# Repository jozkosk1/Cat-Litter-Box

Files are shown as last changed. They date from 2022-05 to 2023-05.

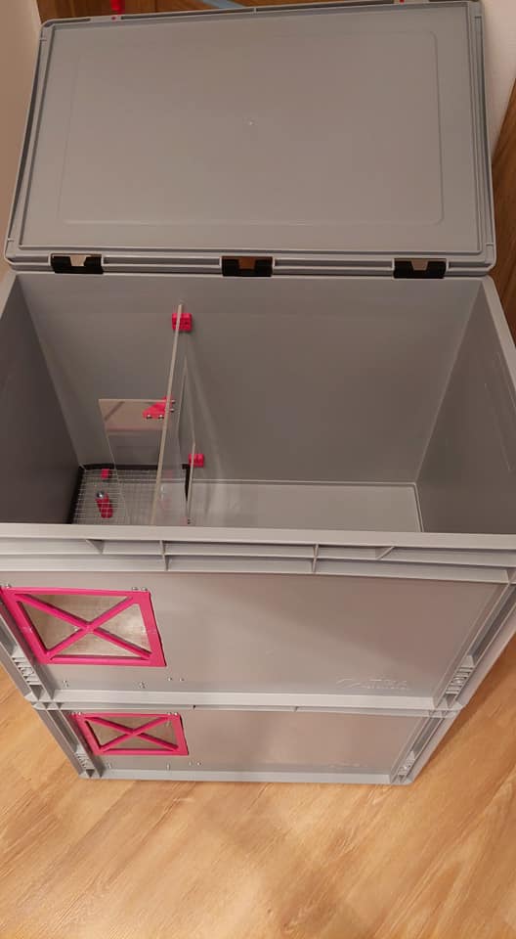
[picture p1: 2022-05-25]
Pictures/279841753_143606158199909_1568186898167949004_n.jpg

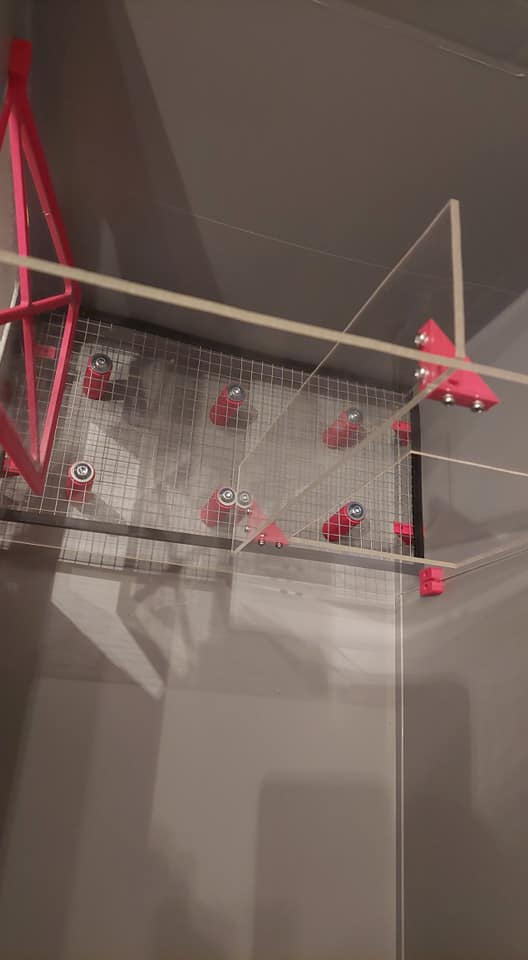
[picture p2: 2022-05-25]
Pictures/279782713_143606121533246_8742560431006277898_n.jpg

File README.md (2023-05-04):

# Cat-Litter-Box
This project is distributed under the GPL v3. <br />
Oversized 3D printed parts (doors) are optimized for the Prusa MINI printer.<br />
This project was created in cooperation with [Monelline](https://www.facebook.com/profile.php?id=100076515751206).<br />
To download the entire package, click on **CODE** > **Download ZIP**.

# Parts

 - Euro Box 60x40x42 cm  ([with](https://www.tbaplast.cz/products/euro-container-with-lid-60x40x435-cm_closed%20handles) or [without](https://www.tbaplast.cz/products/euro-container-closed-handles-60x40x42cm) lid)
 - 5mm thick plexi glass
 - Screw  DIN 7985 M3x10 - 30 pieces
 - Screw ISO 7380 M8x10 - 6 pieces
 - Nut DIN 934 M3 - 28 pieces
 - ~~Wire mesh (I used wire mesh with 10mm holes)~~ 3D printed parts: **mriezka_3D_tlac** - 2 pieces and **back** and **front** - 1 piece of each
 - Transparent office foil
 - 3D printed part: **door_bottom** - 1 piece 
 - 3D printed part: **door_top** - 1 piece
 - 3D printed part: **door_joint** - 1 piece
 - 3D printed part: **door_joint_mirror** - 1 piece
 - 3D printed part: **leg** - 6 pieces
 - 3D printed part: **plexi_holder** - 4 pieces
 - 3D printed part: **plexi_90deg_holder** - 6 pieces

# Manufacturing process

 1. Cut and drill holes in the Euro Box based on the drawings. There are also 1:1 drawings on A3 papers that you can print, cut out and use for easy marking on the box.
 2. Cut **plexi_wall_1** and **plexi_wall_2** according to the drawings. There are also 1:1 drawings.
 3. Cut the thread into **door_joint** and **door_joint_mirror** according to drawing.
 4. Cut the thread into **leg** according to drawing.
 5. Glue the **door_bottom** and **door_top with** a second glue.
 6. According to the notch in the door, cut out and glue the transparent office foil with a second glue.
 7. Install all **plexi_holder**s  on the box. 
 8. Install 4 pieces of **plexi_90deg_holder**s on the box.
 9. Screw the bolt into the thread in **door_joint** and **door_joint_mirror**.
 10. Install one of the joint on the box. 
 11. Complete the door assembly and install the second joint on the box.  
 12. Complete wall assembly (**plexi_wall_1**, **plexi_wall_2**, **plexi_90deg_holder**)
 13. ~~Cut a mesh with an approximate size of 360x185mm.~~ Assemble the printed parts of the grid.
 14. Tighten the **leg**s to the mesh with the screws.
 15. Insert mesh into the box.
 16. Insert plexi_wall assembly into the box.

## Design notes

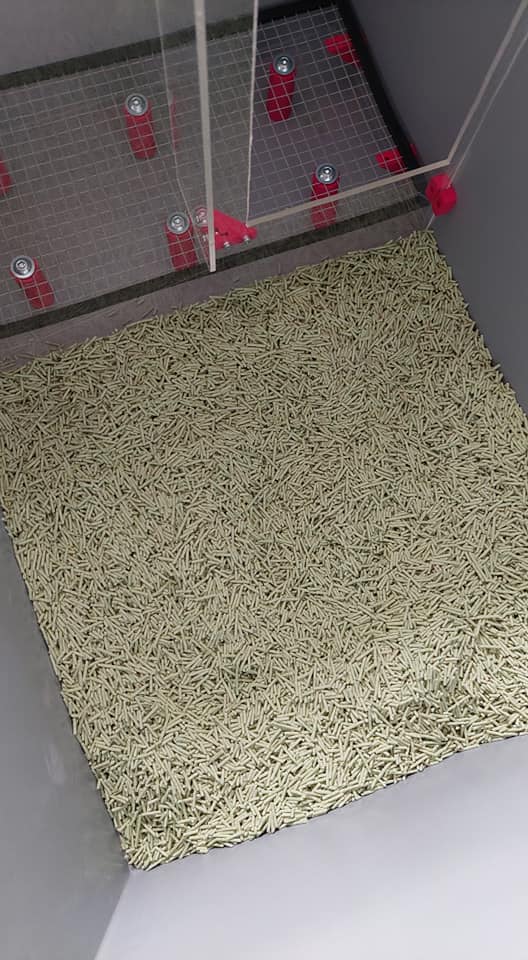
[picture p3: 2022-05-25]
Pictures/279750805_143606194866572_7029943509886688833_n.jpg

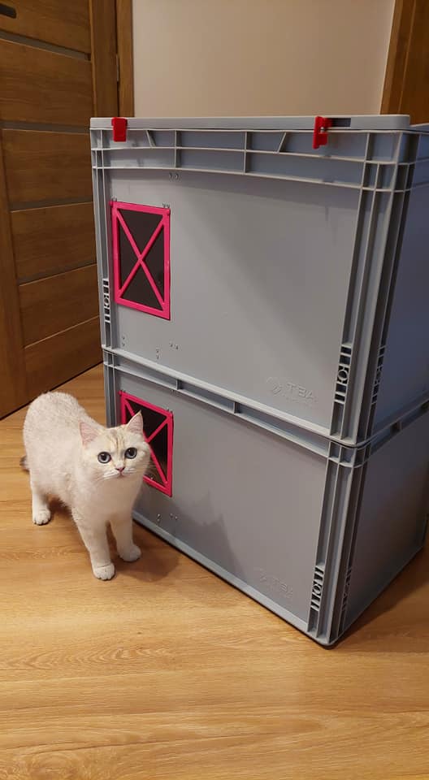
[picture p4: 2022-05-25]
Pictures/279862819_143605988199926_5207650037071910049_n.jpg

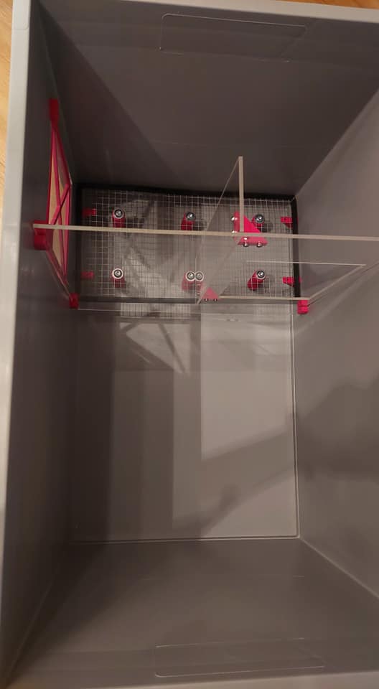
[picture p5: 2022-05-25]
Pictures/279847303_143606091533249_7798021136771881791_n.jpg

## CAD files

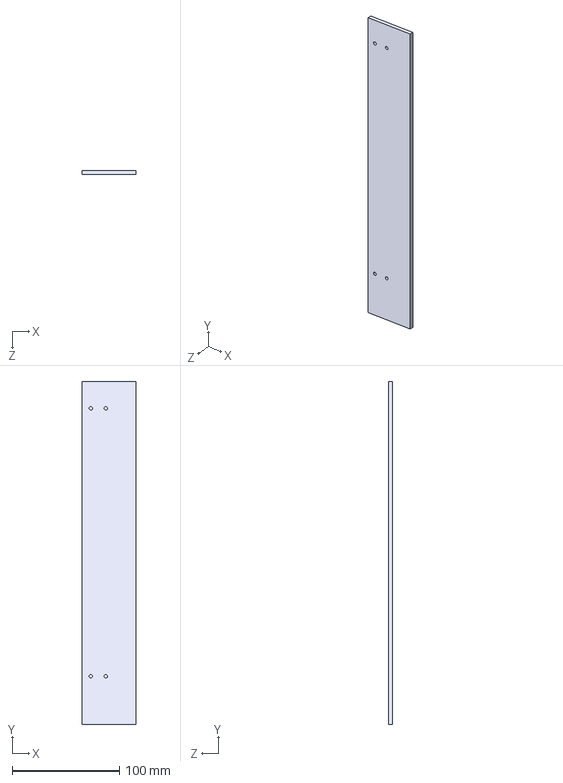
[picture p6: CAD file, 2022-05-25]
3D_data/STEP/plexi_wall_2.STEP
50.0 x 320.0 x 4.00 mm

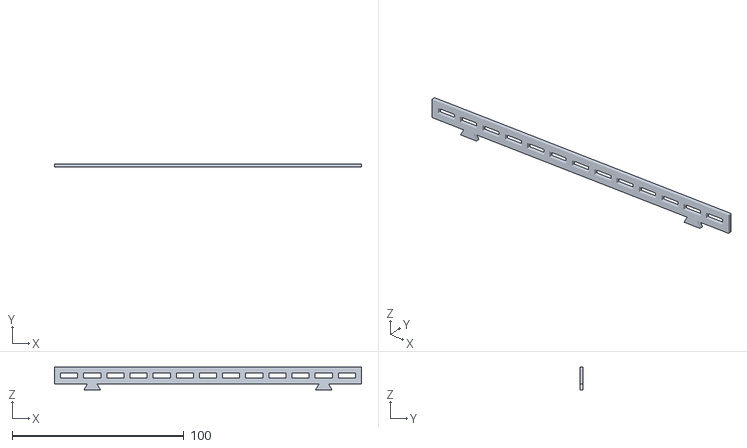
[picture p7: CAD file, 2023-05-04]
3D_data/STL/mriezka_3D_tlac_front.STL
179.0 x 2.00 x 13.4

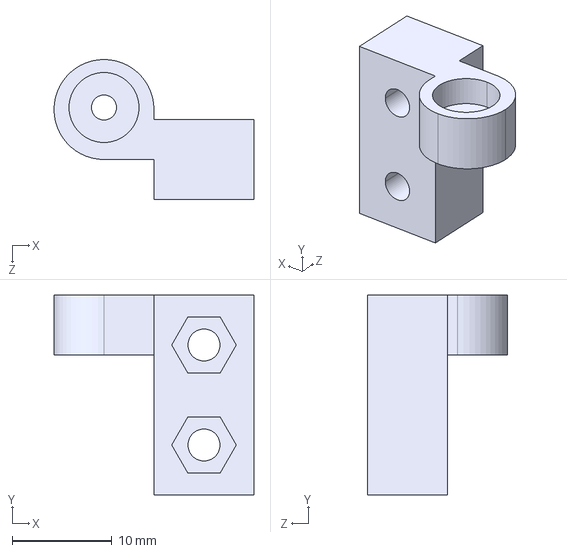
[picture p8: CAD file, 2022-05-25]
3D_data/STEP/door_joint.STEP
20.0 x 20.0 x 14.0 mm

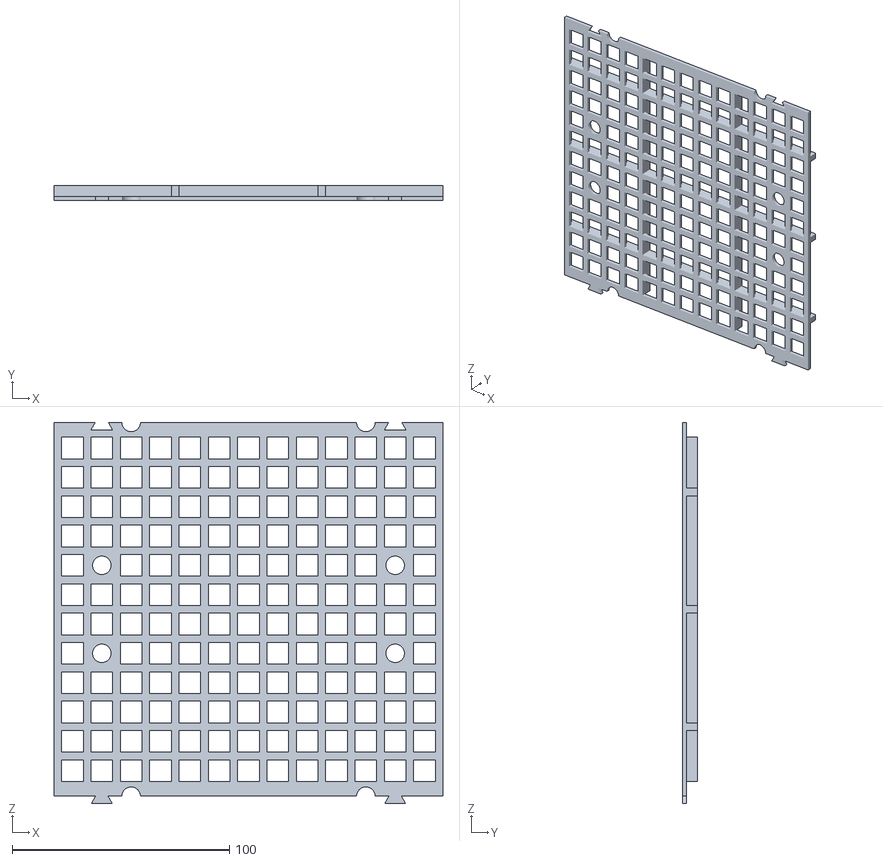
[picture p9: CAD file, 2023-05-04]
3D_data/STL/mriezka_3D_tlac.STL
179.0 x 7.00 x 175.4

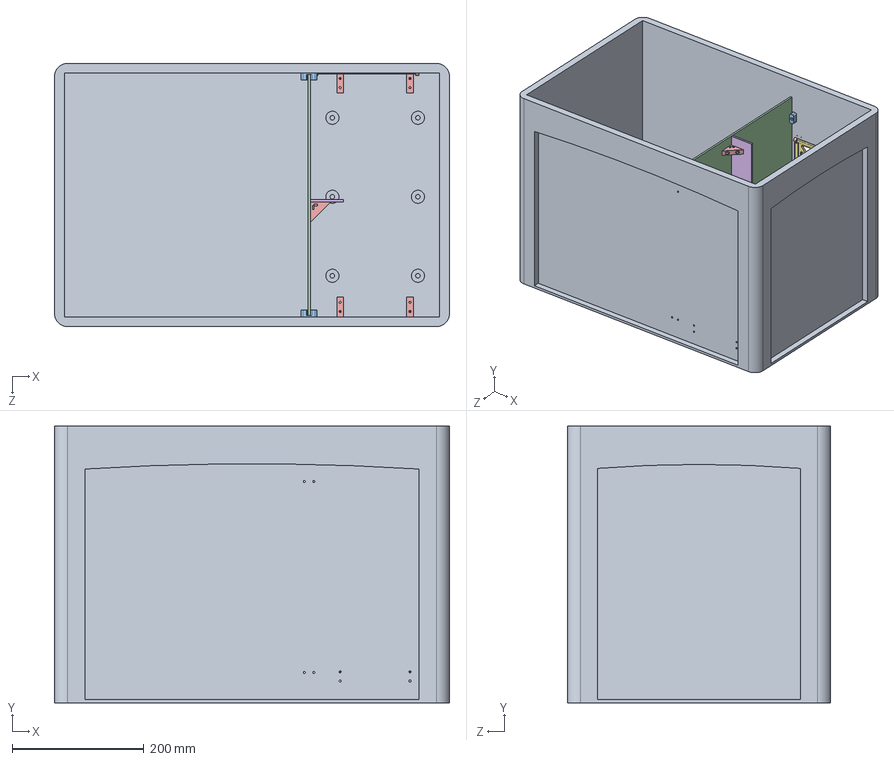
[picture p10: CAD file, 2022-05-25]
3D_data/STEP/Cat-Litter-Box.STEP
600.0 x 420.0 x 400.0 mm
Europrepravka
pant_hore
Mirrorpant_hore
plexi_holder x 4
priecka
uholnik x 6
bludisko
dvierka_2
leg x 6

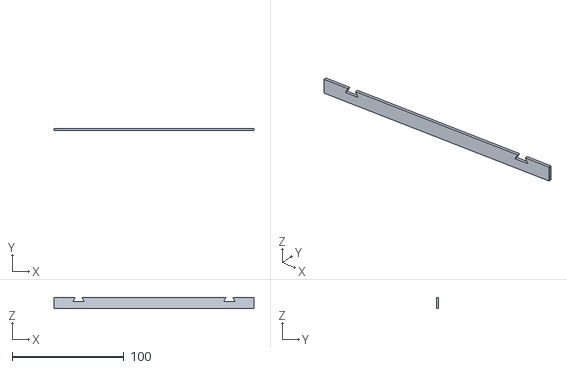
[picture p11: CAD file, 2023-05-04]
3D_data/STL/mriezka_3D_tlac_back.STL
179.0 x 2.00 x 10.0

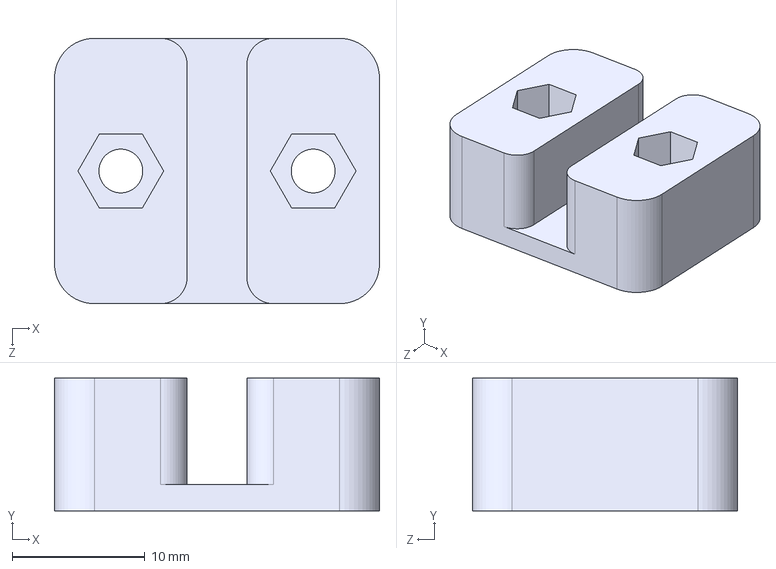
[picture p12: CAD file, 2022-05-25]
3D_data/STEP/plexi_holder.STEP
24.5 x 10.0 x 20.0 mm

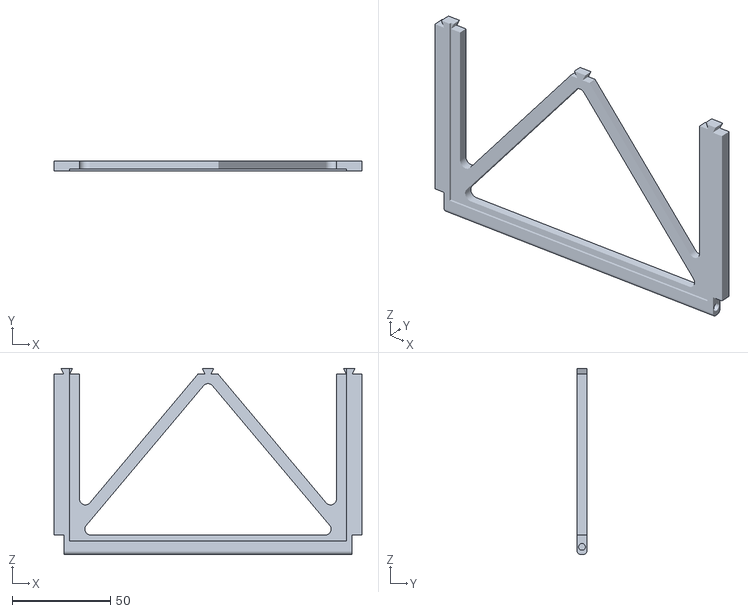
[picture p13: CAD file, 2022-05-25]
3D_data/STL/door_top.STL
157.0 x 5.00 x 95.0

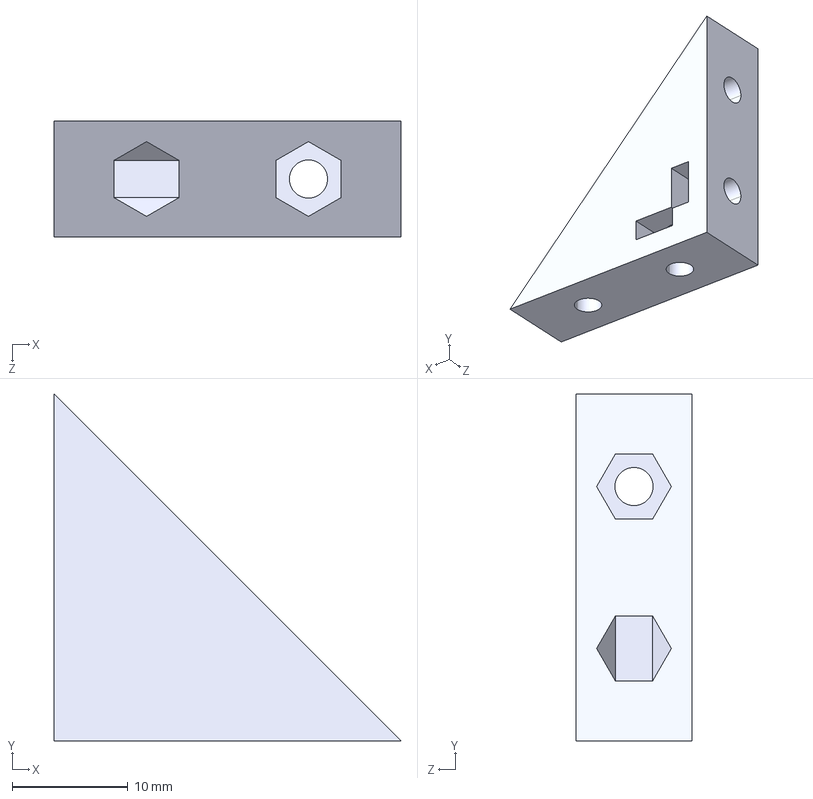
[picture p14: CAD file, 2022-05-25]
3D_data/STEP/plexi_90deg_holder.STEP
30.0 x 30.0 x 10.0 mm

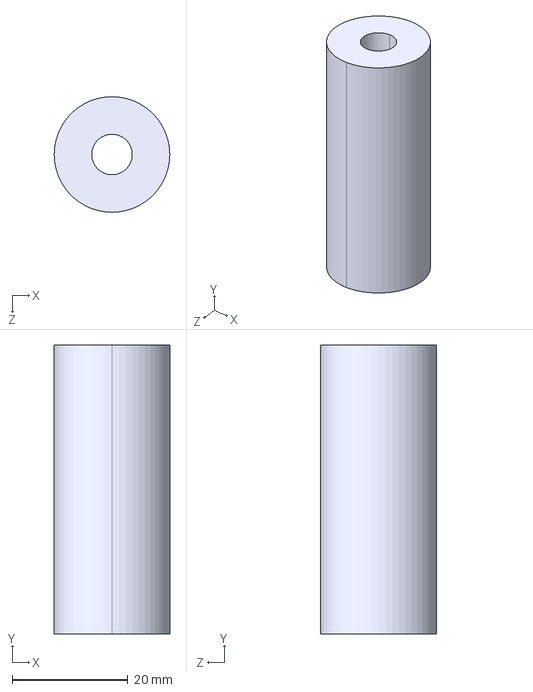
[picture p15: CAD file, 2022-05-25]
3D_data/STEP/leg.STEP
20.0 x 50.0 x 20.0 mm

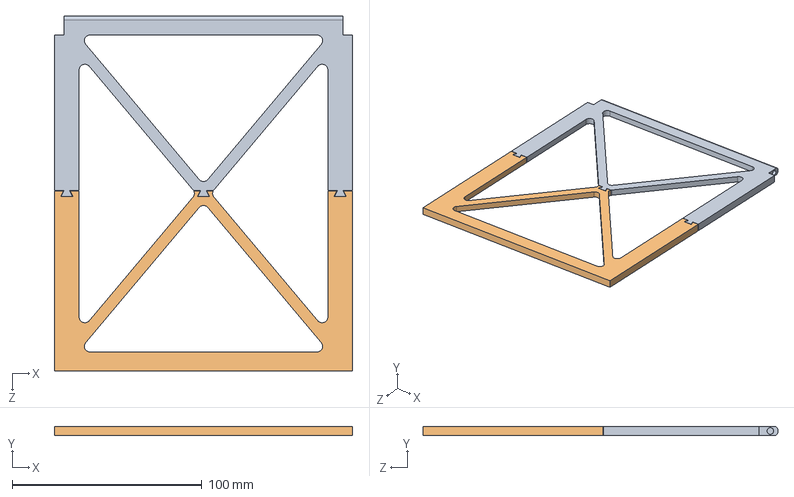
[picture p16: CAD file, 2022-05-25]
3D_data/STEP/door.STEP
157.0 x 5.00 x 187.0 mm

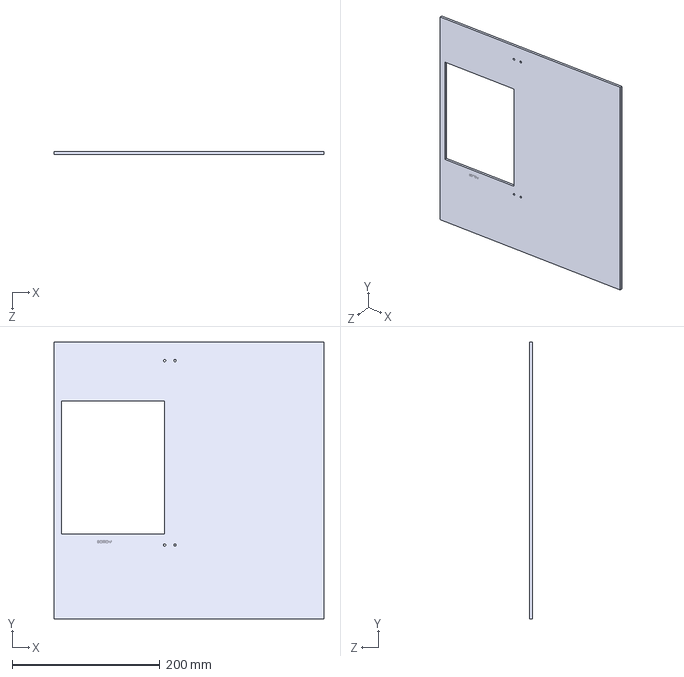
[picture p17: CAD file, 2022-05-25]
3D_data/STEP/plexi_wall_1.STEP
366.0 x 375.0 x 4.00 mm

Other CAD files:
3D_data/STL/door_bottom.STL
3D_data/STEP/door_joint_mirror.STEP
3D_data/STL/door_joint.STL
3D_data/STL/door_joint_mirror.STL
3D_data/STL/leg.STL
3D_data/STL/plexi_90deg_holder.STL
3D_data/STL/plexi_holder.STL

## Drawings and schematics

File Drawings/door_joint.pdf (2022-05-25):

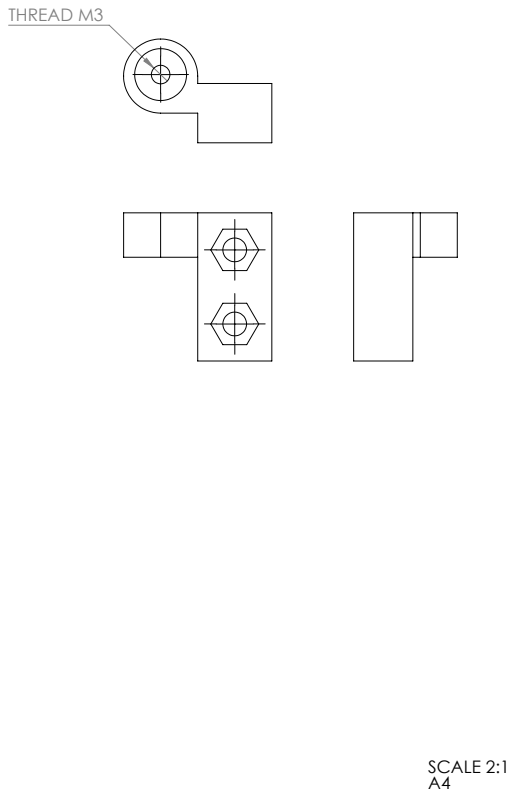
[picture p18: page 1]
THREAD M3; SCALE 2:1

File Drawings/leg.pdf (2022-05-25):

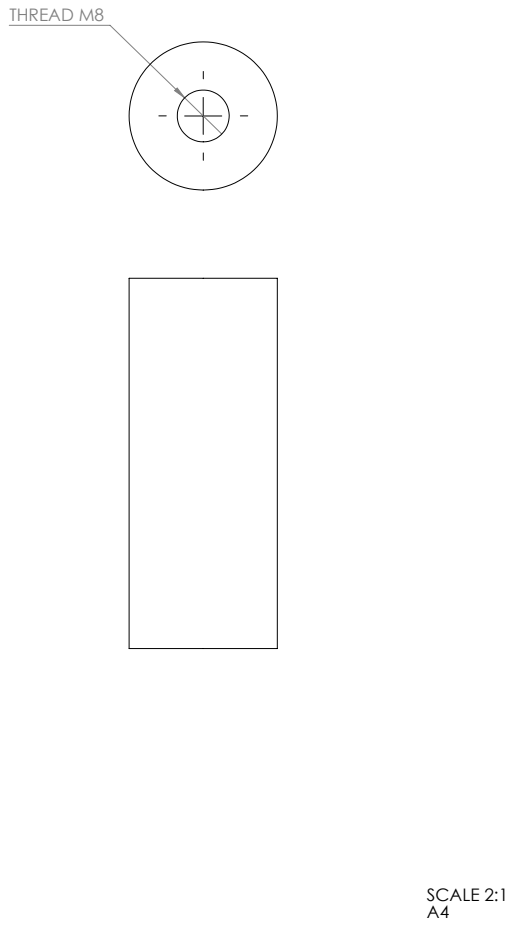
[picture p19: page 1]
THREAD M8; SCALE 2:1

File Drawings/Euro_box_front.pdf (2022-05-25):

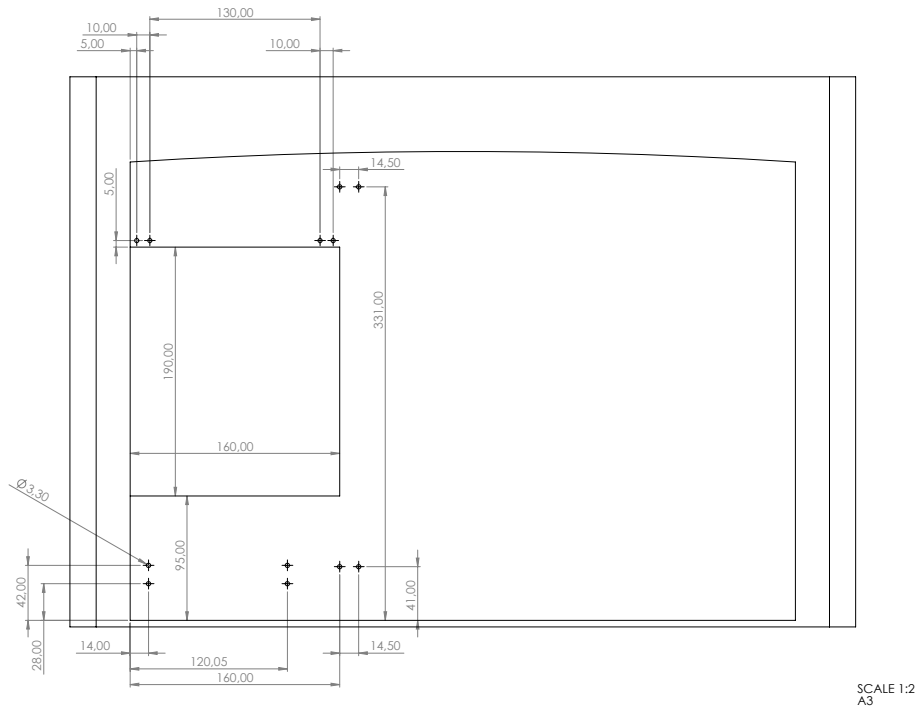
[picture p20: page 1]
SCALE 1:2

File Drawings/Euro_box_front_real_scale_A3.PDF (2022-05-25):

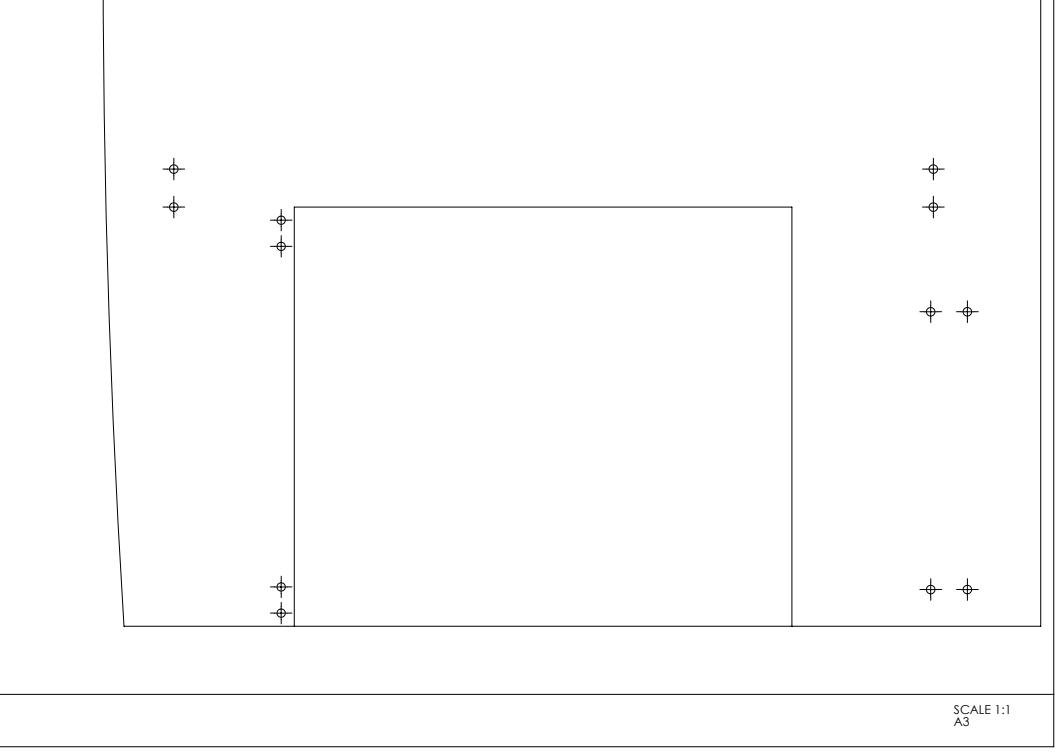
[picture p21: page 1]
SCALE 1:1

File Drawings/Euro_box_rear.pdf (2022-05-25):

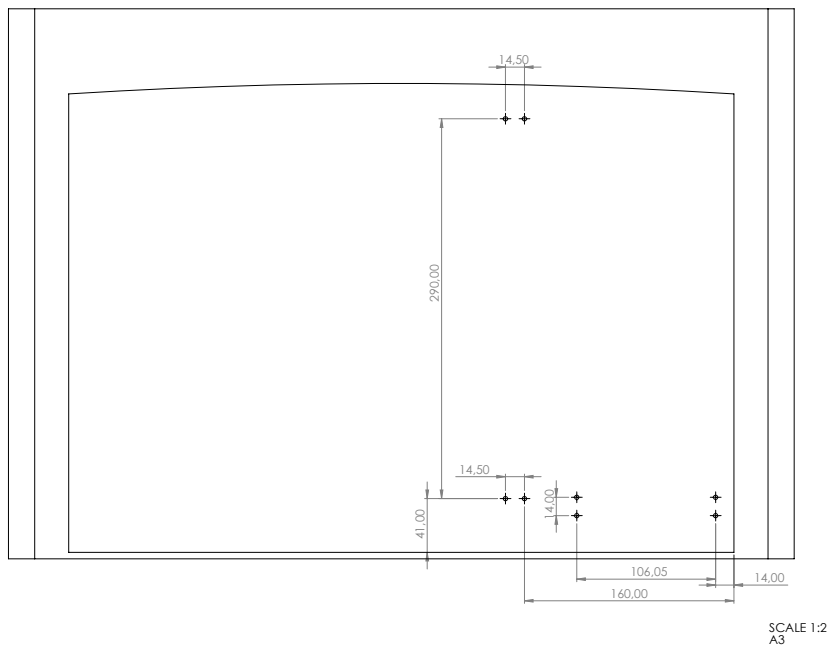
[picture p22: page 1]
SCALE 1:2

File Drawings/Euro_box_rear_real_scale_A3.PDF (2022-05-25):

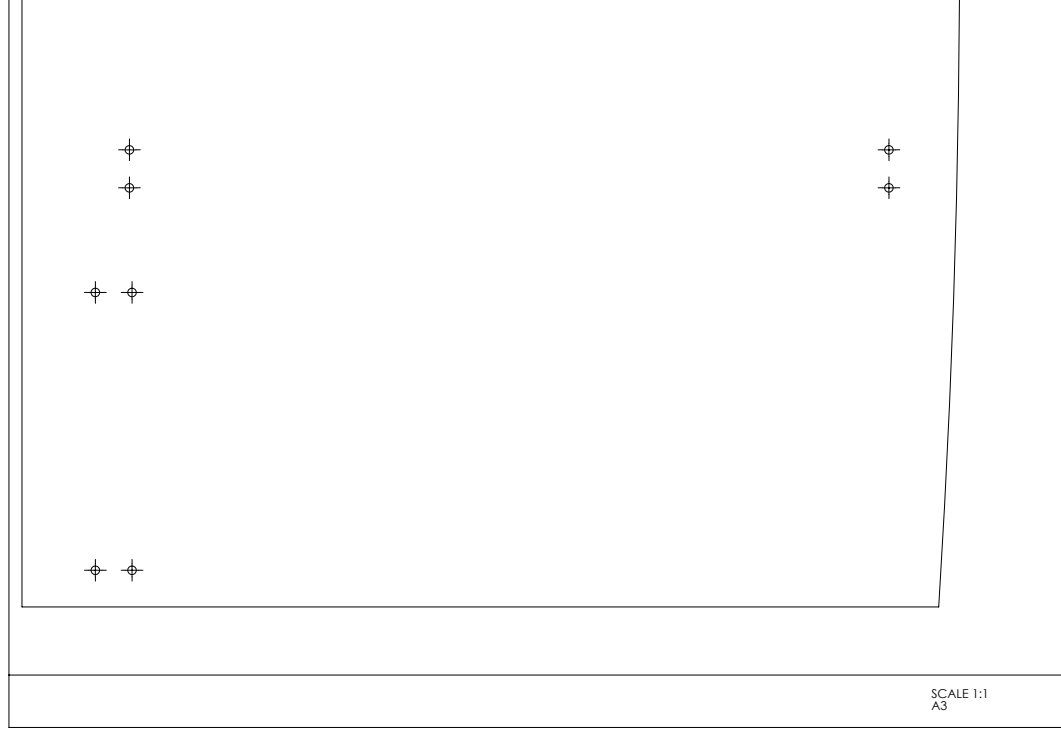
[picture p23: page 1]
SCALE 1:1

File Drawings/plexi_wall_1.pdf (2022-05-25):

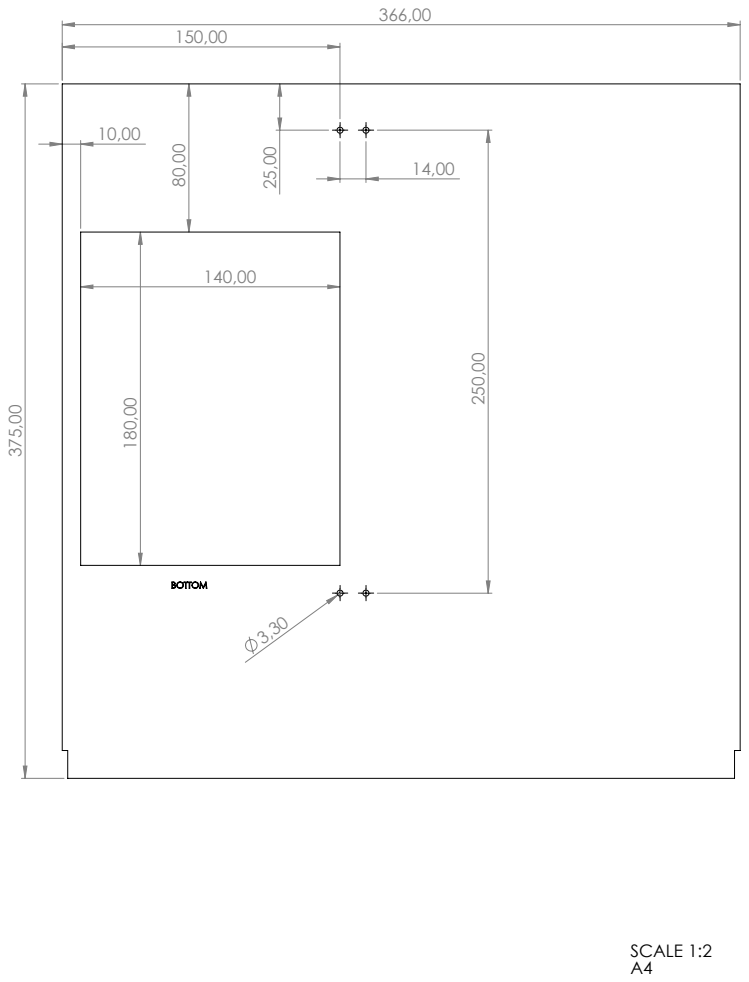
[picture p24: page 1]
SCALE 1:2

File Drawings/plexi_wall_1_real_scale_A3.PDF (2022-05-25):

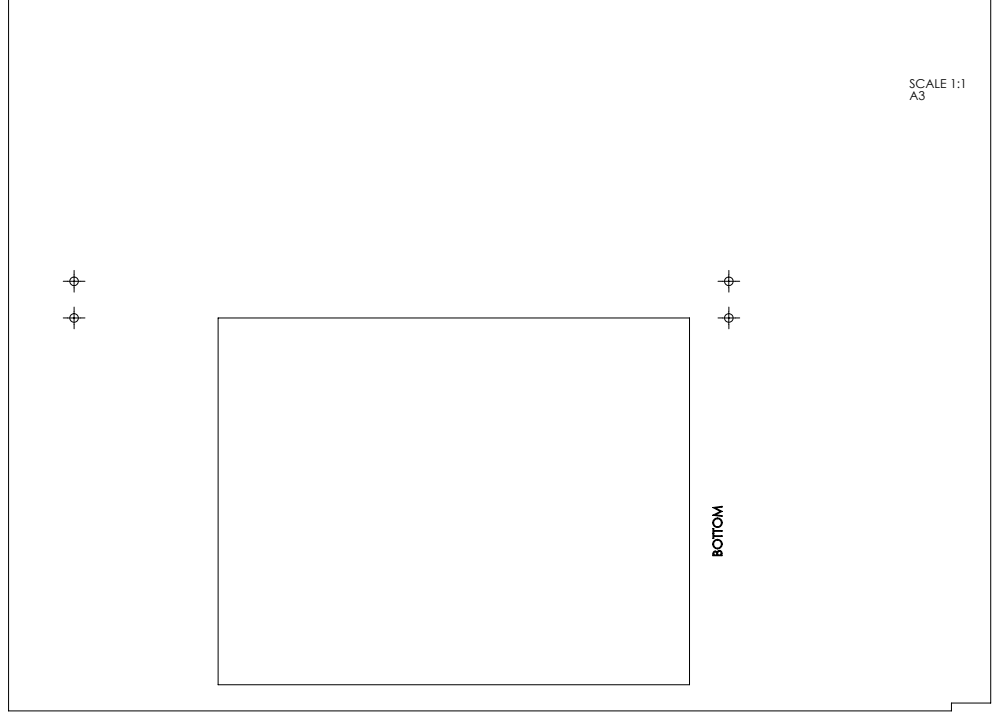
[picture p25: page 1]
SCALE 1:1

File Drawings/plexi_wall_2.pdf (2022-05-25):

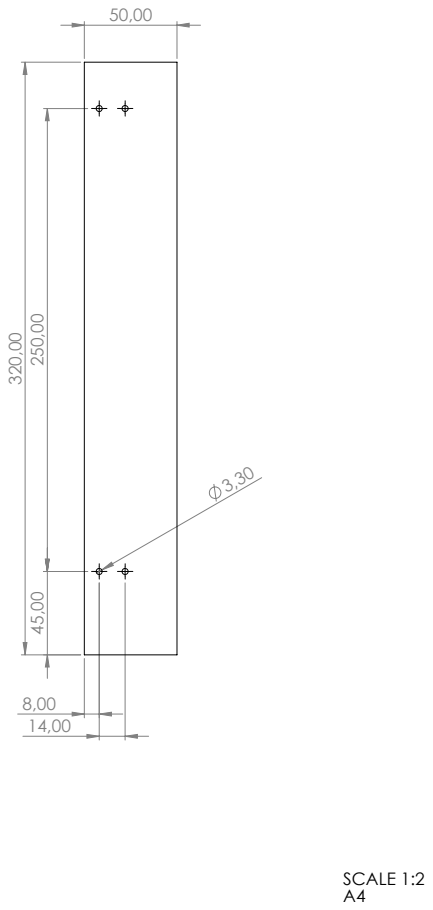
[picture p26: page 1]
SCALE 1:2

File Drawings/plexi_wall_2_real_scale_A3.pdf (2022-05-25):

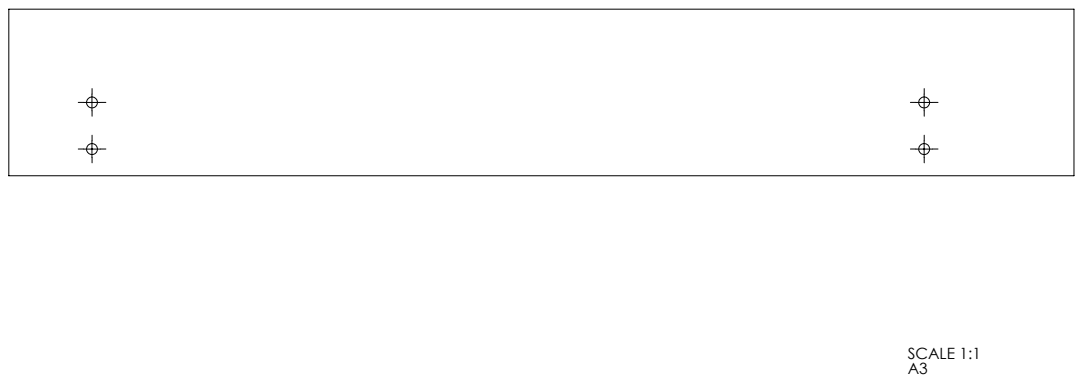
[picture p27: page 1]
SCALE 1:1

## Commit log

2022-05-25 release 1.0
    [Cat-Litter-Box.STEP, door.STEP, door_bottom.STL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]
2023-05-04 release 1.1
    net redesign
    [mriezka_3D_tlac.STL, mriezka_3D_tlac_back.STL, mriezka_3D_tlac_front.STL]
